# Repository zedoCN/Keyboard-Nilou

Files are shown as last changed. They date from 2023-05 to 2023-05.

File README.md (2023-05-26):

# Keyboard-Nilou  (KB-Nilou)
 
## 描述  
### 目前实现的功能：  
* usb键盘模拟  
* 系统音量调节  
* 上位机通讯(java kb-nilou-SDK)  
* 语音播放  
* rgb灯效  
* 热插拔键盘座  
* 震动反馈  

### 待填的坑：
* 第7K的扩展(懒得做了)  
* 官方的上位机软件(懒得写了)  

## PCB图：  
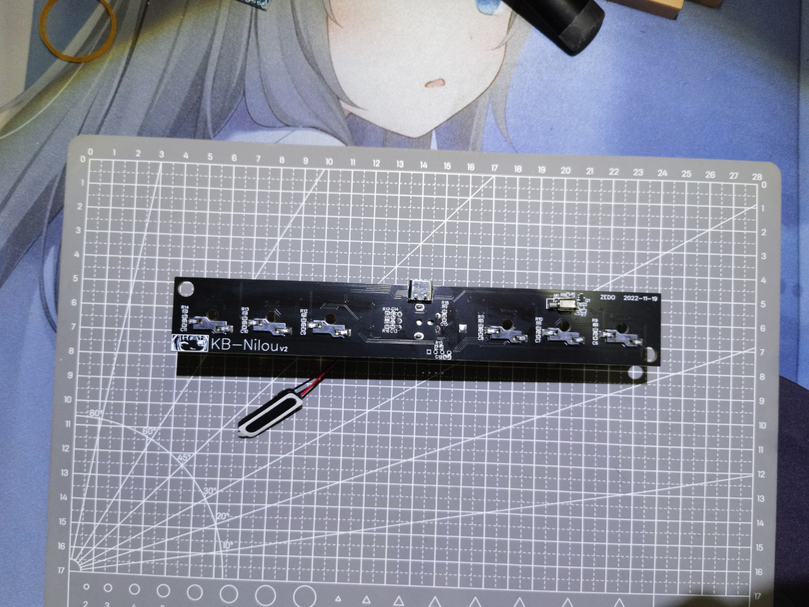
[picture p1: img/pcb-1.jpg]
   
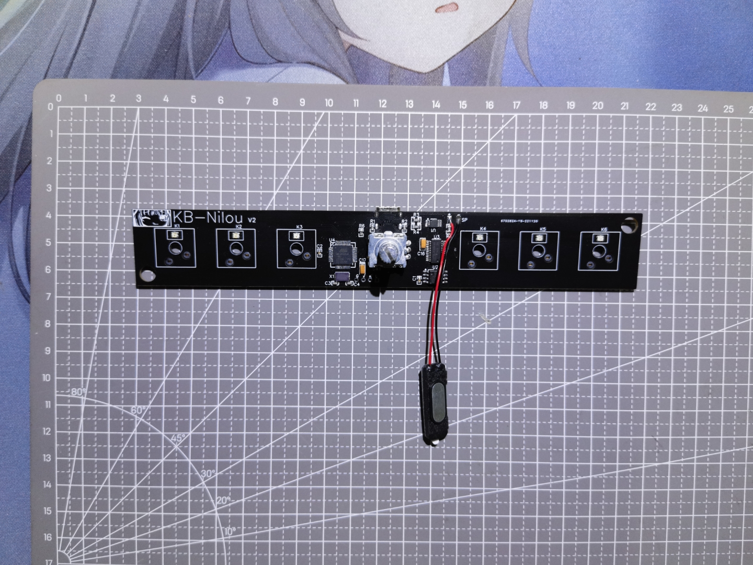
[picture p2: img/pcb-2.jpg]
   

## 渲染图：  

### (初代)  
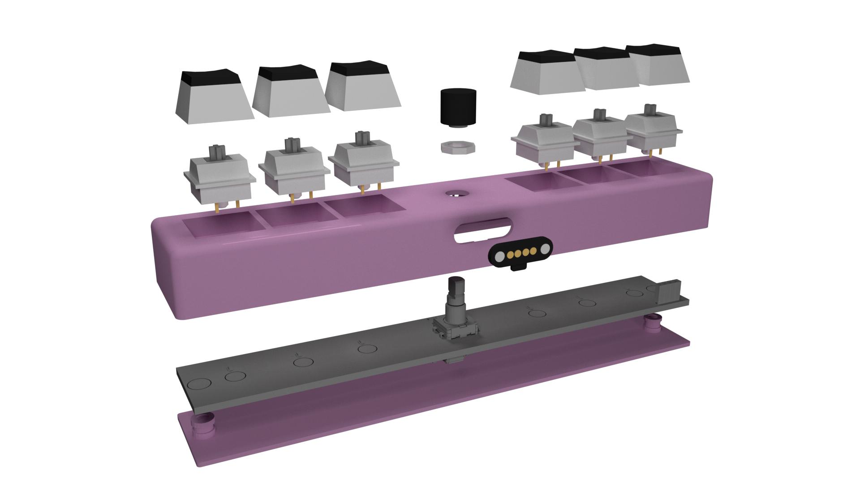
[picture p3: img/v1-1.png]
   

### (第一代)  
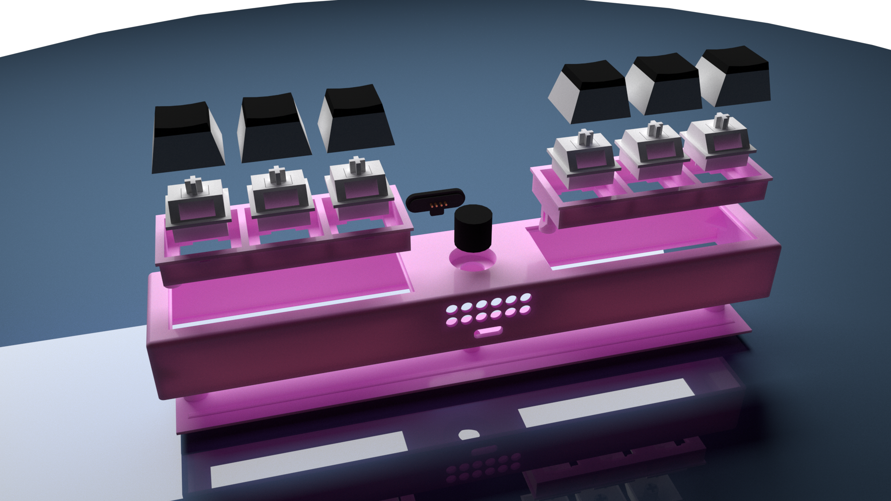
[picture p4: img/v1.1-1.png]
   

### (第二代)  
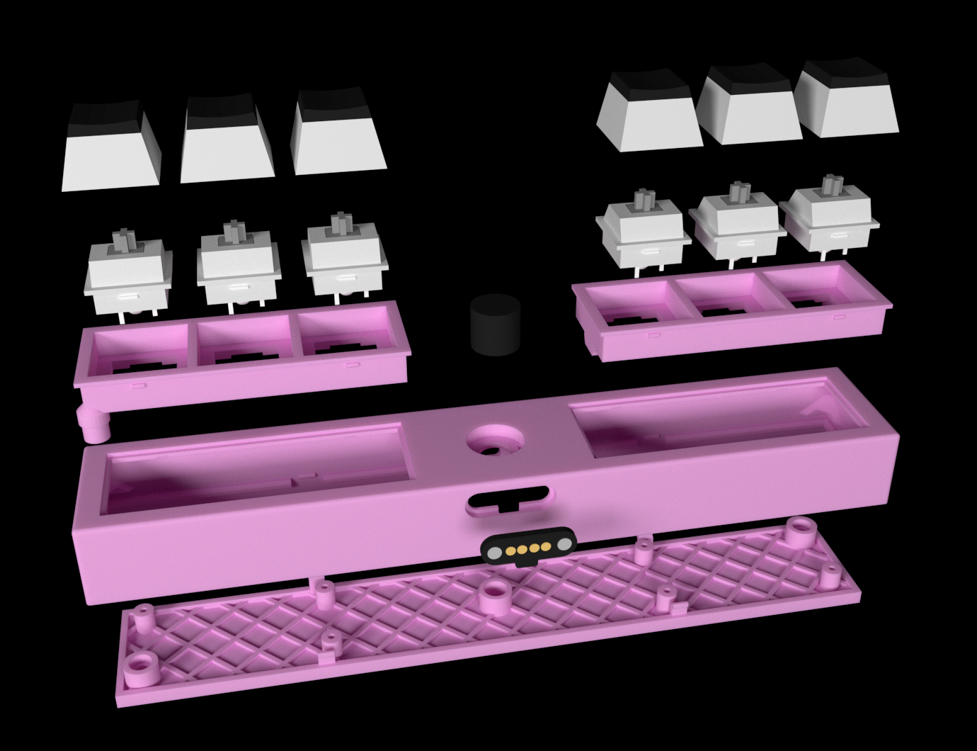
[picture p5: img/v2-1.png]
   

## 实物图：(白色和透明)  
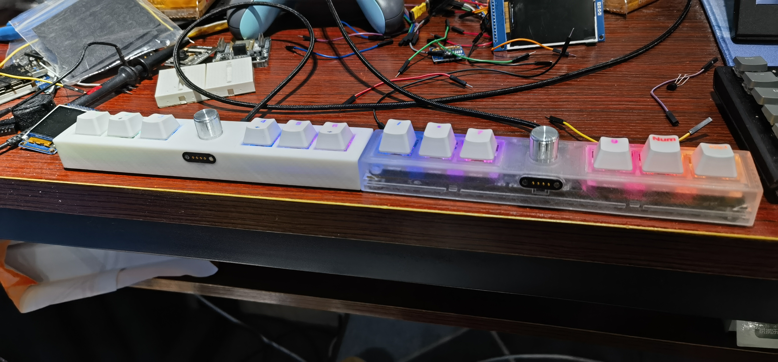
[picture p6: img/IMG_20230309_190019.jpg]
   
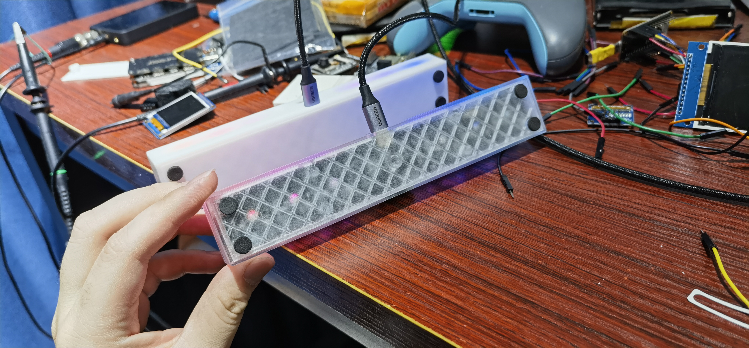
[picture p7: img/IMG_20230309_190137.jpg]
   

## 原理图 [嘉立创](https://oshwhub.com/zedo_cn/jian-pan-wai-she)
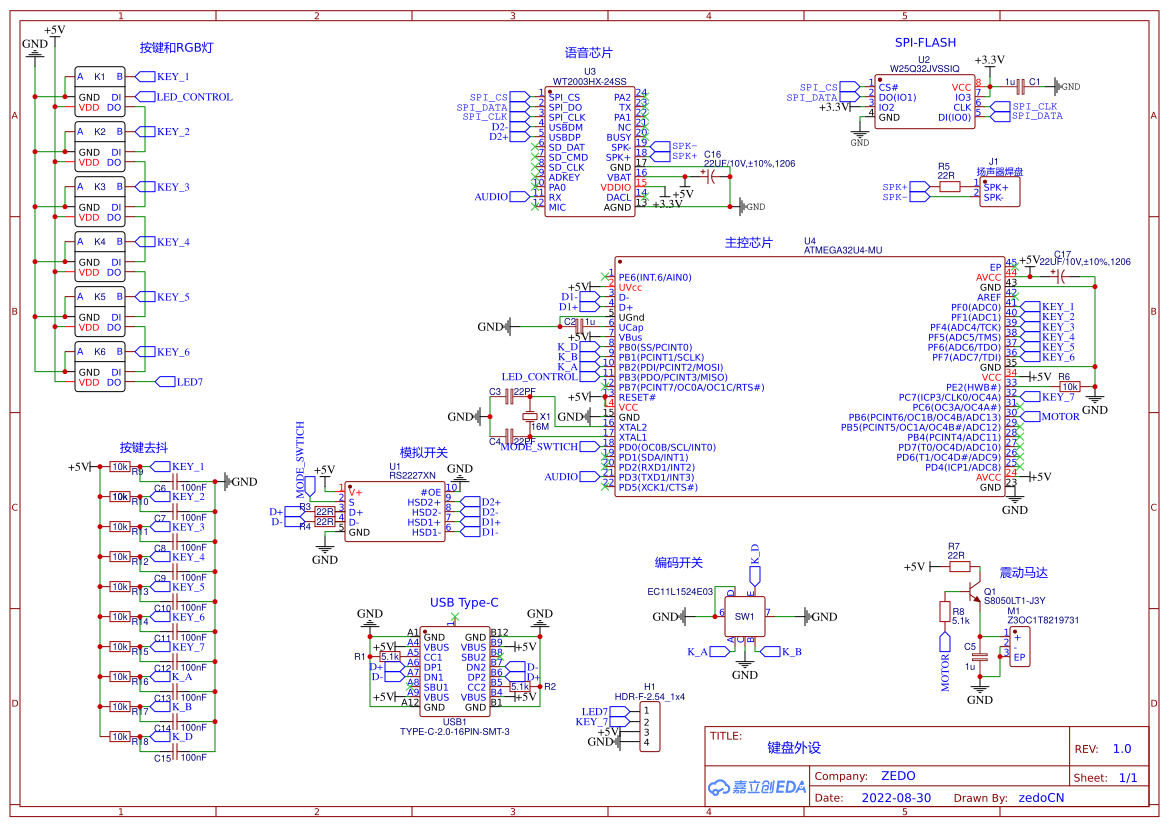
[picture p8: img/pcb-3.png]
   
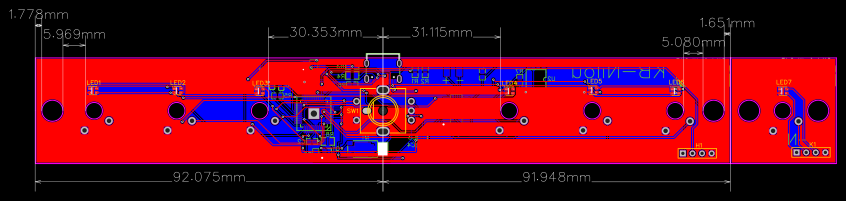
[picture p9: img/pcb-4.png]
   
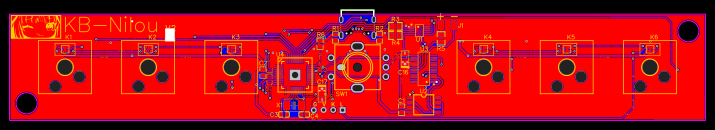
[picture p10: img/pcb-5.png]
   

## 所有的音频

* key音
    > * Kll.mp3  key音
    > * Knya.mp3  key音
    > * Kosu.mp3  key音
    > * Krachel.mp3  key音
    > * Ktshe.mp3  key音
* 其他
    > * Wel.mp3  欢迎
    > * OK.mp3  好
    > * UDSD.mp3  了解
    > * choose.mp3  选择音效
    > * HOc.mp3  上位机连接
    > * HOd.mp3  上位机断开连接
* 数字
    > * Nu0.mp3  数字0
    > * ...
    > * Nu10.mp3  数字10
* MCh.mp3  模式选择
    > * MAu.mp3  音频编辑模式
    > * MNo.mp3  普通模式
    > * MSe.mp3  设置模式
    >   > * SCh.mp3  设置选择
    >   > * SVo.mp3  音量设置
    >   > * Ske.mp3  key音设置
    >   > * SLm.mp3  灯光模式
    >   >   > * SLm0.mp3  0无灯光
    >   >   > * SLm1.mp3  1常亮
    >   >   > * SLm2.mp3  2独亮
    >   >   > * SLm3.mp3  3独亮闪烁
    >   > * SLc.mp3  灯光颜色
    >   >   > * SLc0.mp3  0自定义颜色
    >   >   > * SLc1.mp3  1七彩渐变
    >   >   > * SLc2.mp3  2七彩渐变流水
    >   >   > * SLc3.mp3  3随机
    >   >   > * SLc4.mp3  4纯红
    >   >   > * ...
    >   >   > * SLc11.mp3  11纯白
    >   > * SLb.mp3  灯光亮度
    >   > * SEx.mp3  退出设置
    >   > * SSh.mp3  震动设置
    >   >   > * SSh0.mp3  0无震动
    >   >   > * SSh1.mp3  1轻震动
    >   >   > * SSh2.mp3  2重震动
    >   > * SEx.mp3  退出设置

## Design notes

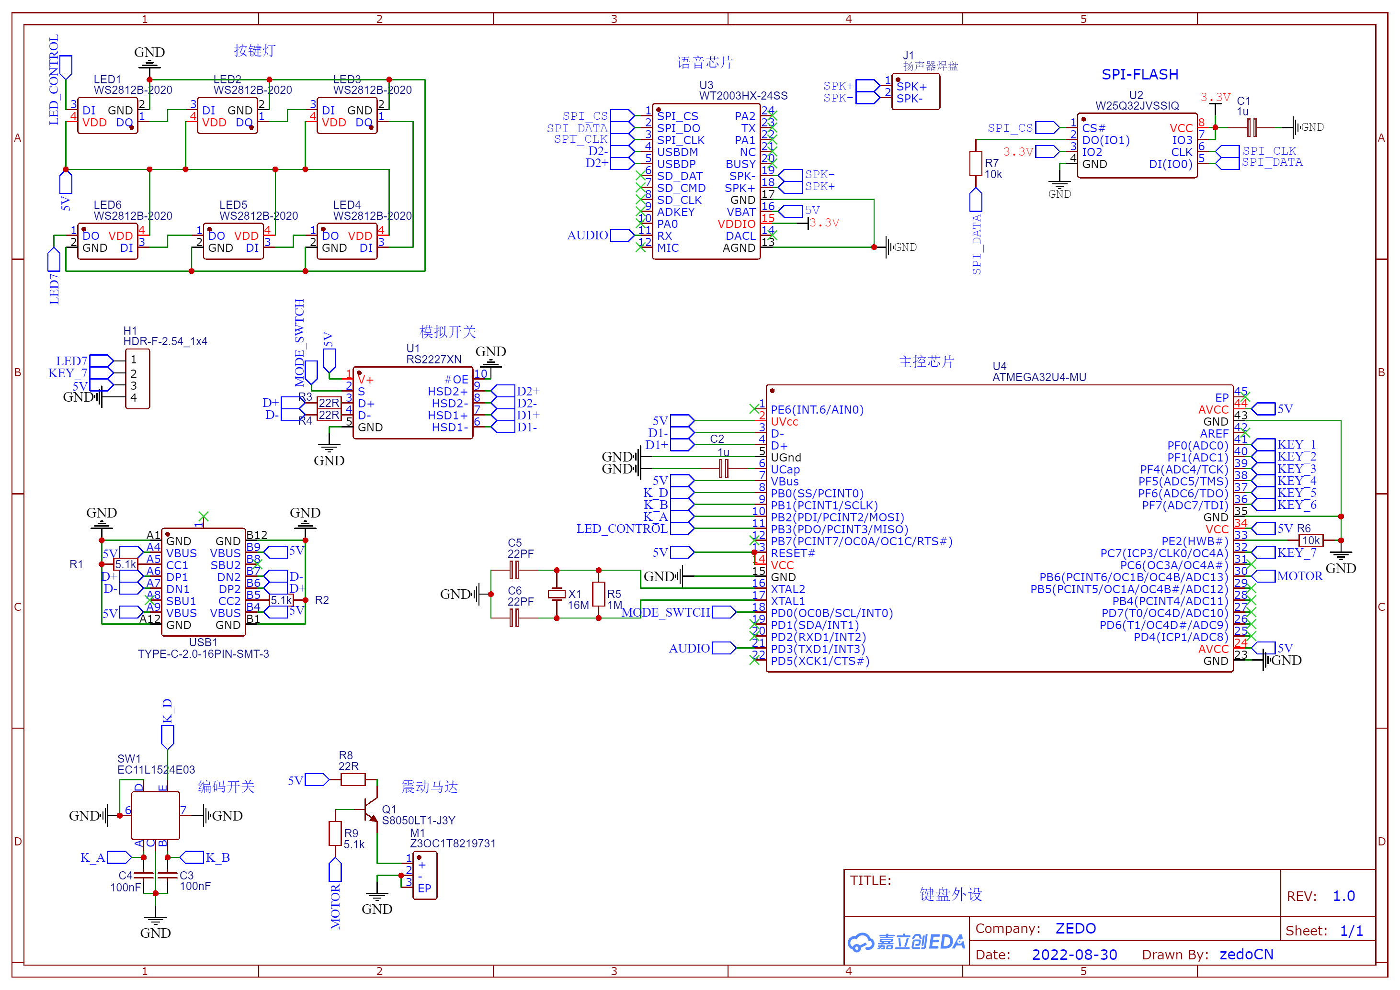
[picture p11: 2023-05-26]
Schematic_键盘外设_2022-09-01.png

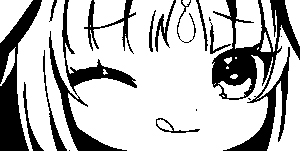
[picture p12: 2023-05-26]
100828284_p2.jpg

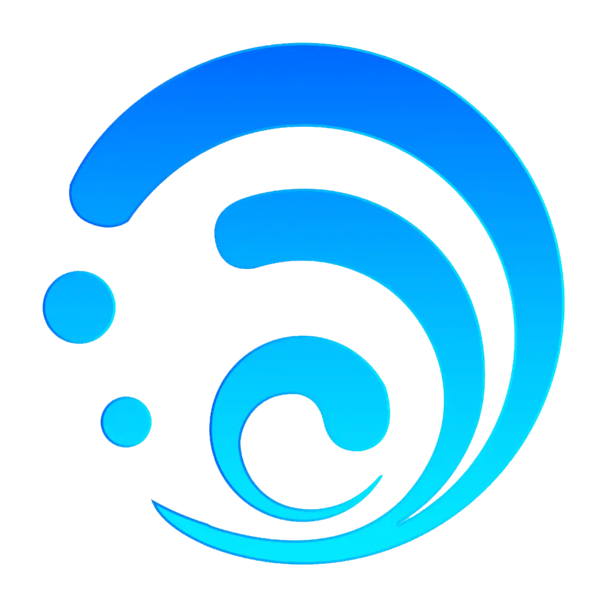
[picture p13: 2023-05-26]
水.png

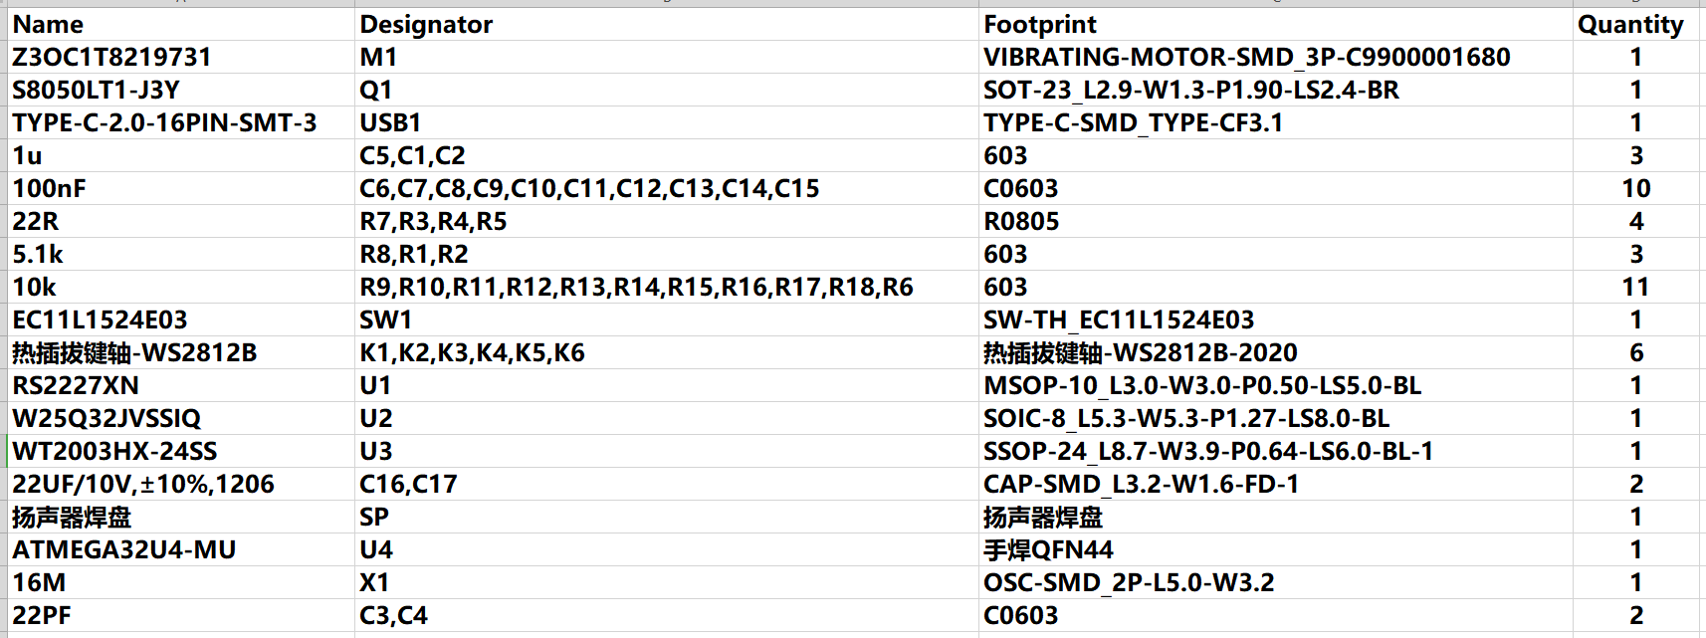
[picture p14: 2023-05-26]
KBNilou.png

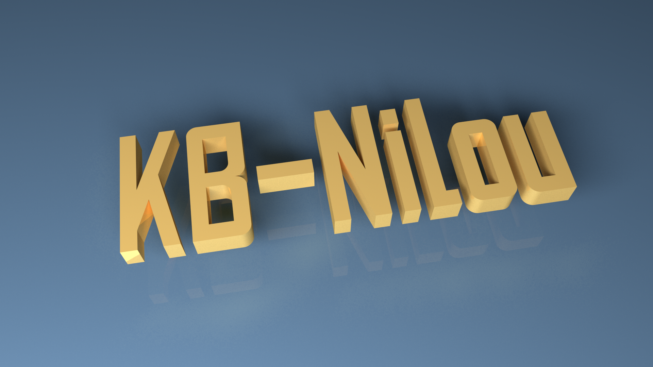
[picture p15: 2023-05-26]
KB-Nilou.png

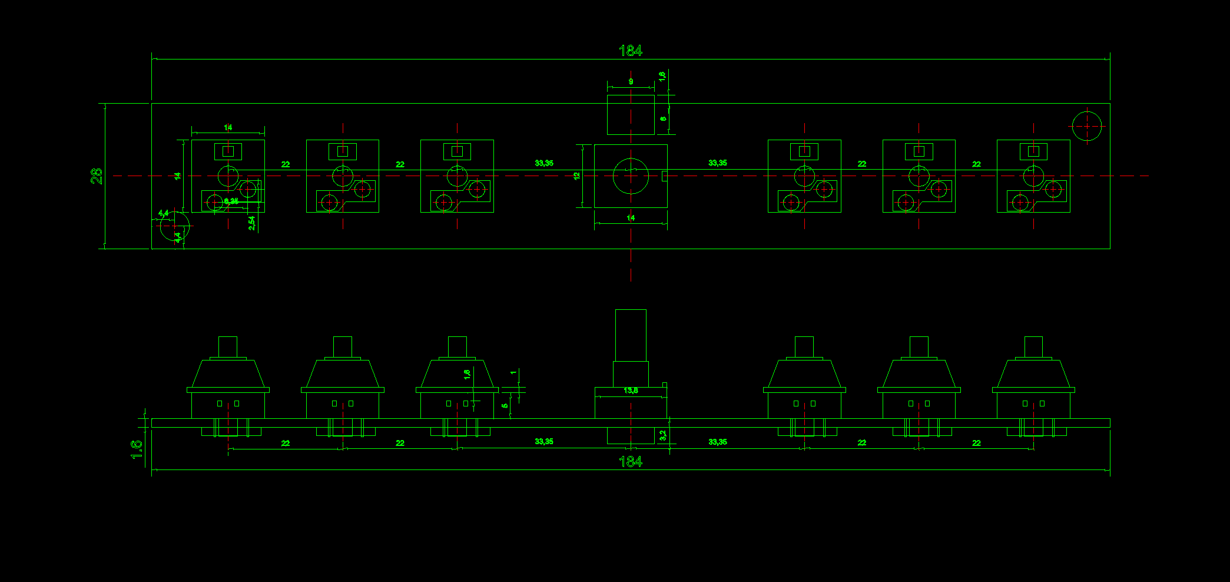
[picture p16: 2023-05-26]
KB-Nilou-v2.png

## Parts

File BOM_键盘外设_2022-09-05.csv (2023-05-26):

ID | Name | Designator | Footprint | Quantity | Manufacturer Part | Manufacturer | Supplier | Supplier Part | Price | Pins
1 | 1u | C1,C2 | 0603 | 2 |  |  |  |  |  | 2
2 | 100nF | C3,C4 | C0603 | 2 | 0603B104K500NT | FH | LCSC | C30926 | 0.0076 | 2
3 | 22PF | C5,C6 | C0603 | 2 |  |  |  |  |  | 2
4 | HDR-F-2.54_1x4 | H1 | HDR-F-2.54_1X4 | 1 |  |  | LCSC | C225501 | 0.5575 | 4
5 | 扬声器焊盘 | J1 | 扬声器焊盘 | 1 |  |  |  |  |  | 2
6 | WS2812B-2020 | LED1,LED2,LED3,LED4,LED5,LED6 | LED-SMD_4P-L2.0-W2.0-TL_WS2812B-2020 | 6 | WS2812B-2020 | Worldsemi | LCSC | C965555 | 0.6722 | 4
7 | Z3OC1T8219731 | M1 | VIBRATING-MOTOR-SMD_3P-C9900001680 | 1 | Z3OC1T8219731 | KOTL(金龙机电) | LCSC | C2894731 | 6.7 | 3
8 | S8050LT1-J3Y | Q1 | SOT-23_L2.9-W1.3-P1.90-LS2.4-BR | 1 | S8050LT1-J3Y | FH(风华) | LCSC | C2962087 | 0.1091 | 3
9 | 5.1k | R1,R2,R9 | 0603 | 3 |  |  |  |  |  | 2
10 | 22R | R3,R4,R8 | R0805 | 3 |  |  |  |  |  | 2
11 | 1M | R5 | 0603 | 1 |  |  |  |  |  | 2
12 | 10k | R6,R7 | 0603 | 2 |  |  |  |  |  | 2
13 | EC11L1524E03 | SW1 | SW-TH_EC11L1524E03 | 1 | EC11L1524E03 | ALPSALPINE(阿尔卑斯阿尔派) | LCSC | C2687297 | 5.71 | 7
14 | RS2227XN | U1 | MSOP-10_L3.0-W3.0-P0.50-LS5.0-BL | 1 | RS2227XN | RUNIC( ) | LCSC | C255478 | 1.93 | 10
15 | W25Q32JVSSIQ | U2 | SOIC-8_L5.3-W5.3-P1.27-LS8.0-BL | 1 | W25Q32JVSSIQ | WINBOND | LCSC | C82344 | 2.88 | 8
16 | WT2003HX-24SS | U3 | SSOP-24_L8.7-W3.9-P0.64-LS6.0-BL-1 | 1 | WT2003HX-24SS | null | LCSC | C2841000 |  | 24
17 | ATMEGA32U4-MU | U4 | 手焊QFN44 | 1 | ATMEGA32U4-MU | MICROCHIP | LCSC | C112161 | 28.25 | 45
18 | TYPE-C-2.0-16PIN-SMT-3 | USB1 | TYPE-C-SMD_TYPE-CF3.1 | 1 | TYPE-C-2.0-16PIN-SMT-3 | CIKI(皓富) | LCSC | C2987386 | 0.8706 | 17
19 | 16M | X1 | OSC-SMD_2P-L5.0-W3.2 | 1 | AA08000002 | TXC Corp | LCSC | C331621 | 2.53 | 2

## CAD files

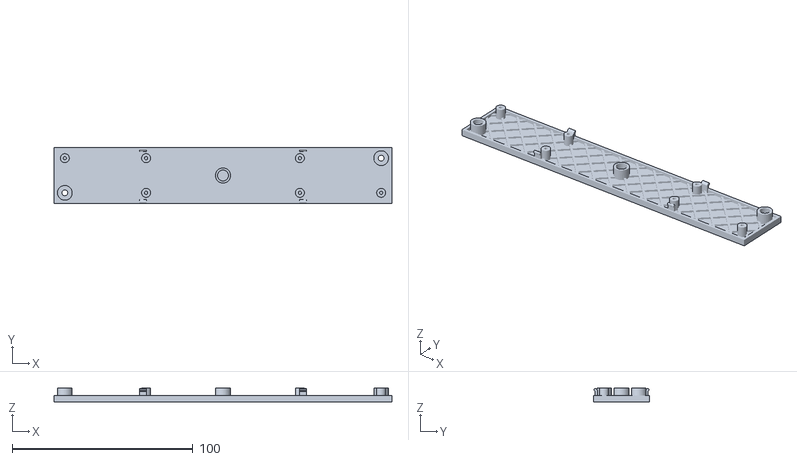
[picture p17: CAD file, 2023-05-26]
2.0/背板.stl
187.2 x 31.2 x 7.65

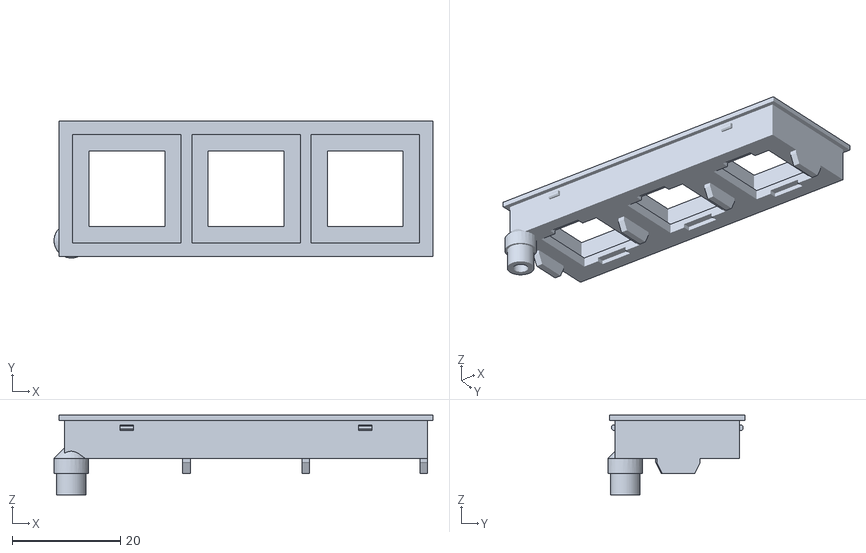
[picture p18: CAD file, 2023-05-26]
2.0/键盘座.stl
70.0 x 25.3 x 14.8

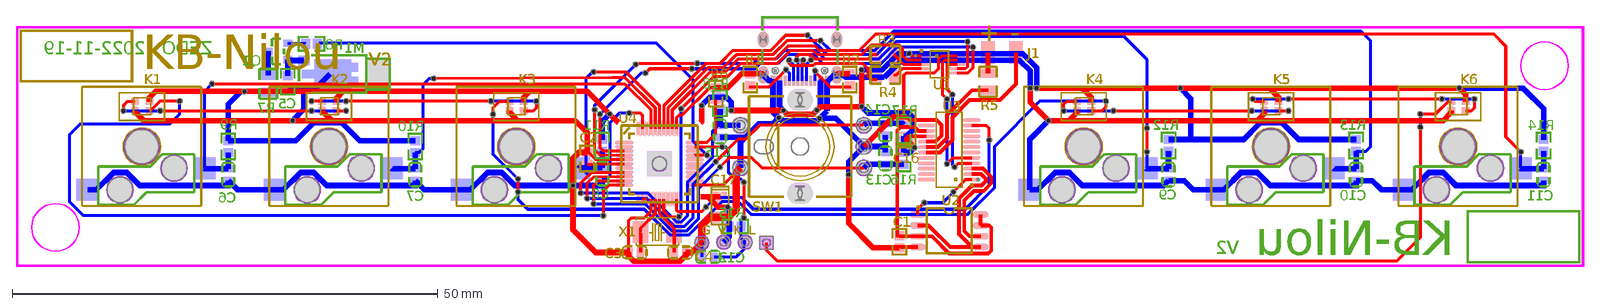
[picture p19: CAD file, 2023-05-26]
pcb/PCB_键盘外设_v2_2023-05-27.dxf
KB-Nilou
ZEDO 2022-11-19
V2
G V K L
M1
Q1
C5
C6
C7
C8
C9
C10
C11
C12
C13
C14
C15
R7
R8
R9
R10
R11
R12
R13
R14
R15
R16
R17
R18
J1
+
-
SW1
K1
K2
K3
K4
K5
K6
R1
C1
R2
R3
R4
U1
U2
U3
C16
C2
R5
R6
U4
X1
C3
C4
C17

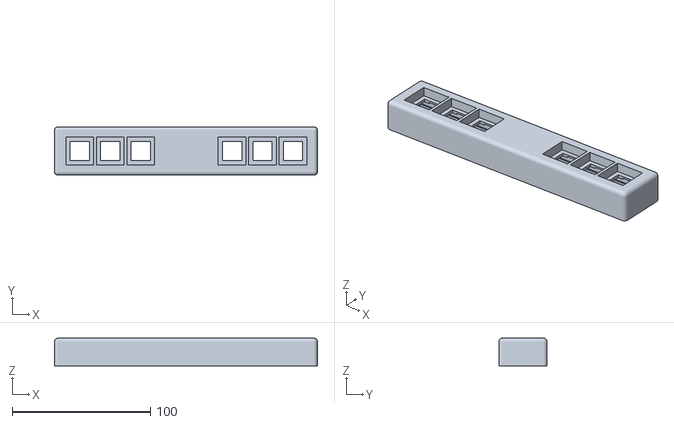
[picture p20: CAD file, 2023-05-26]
按键外设-本体.stl
190.0 x 35.0 x 20.0

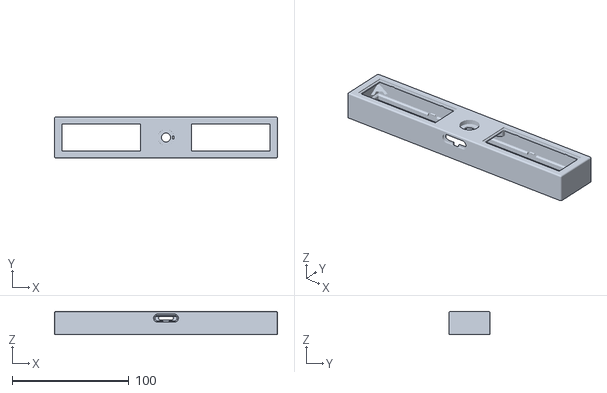
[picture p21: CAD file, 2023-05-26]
2.0/本体-圆角.stl
190.8 x 34.8 x 20.0

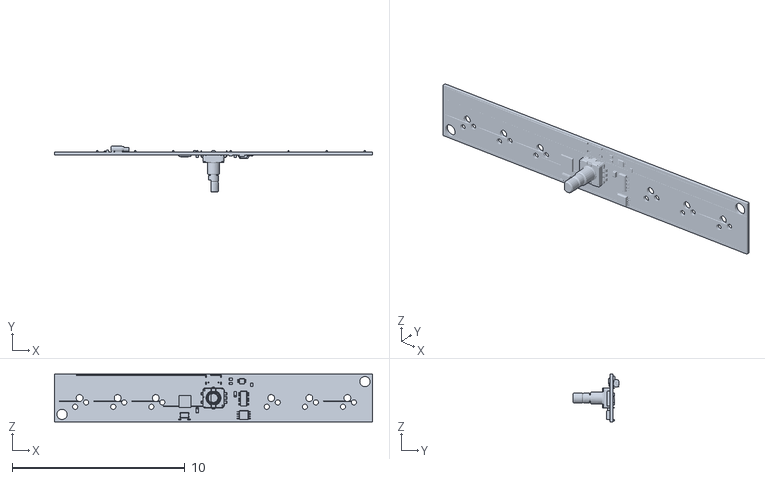
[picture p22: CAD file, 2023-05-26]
OBJ_PCB_键盘外设_1.1V.stl
18.4 x 2.66 x 2.78

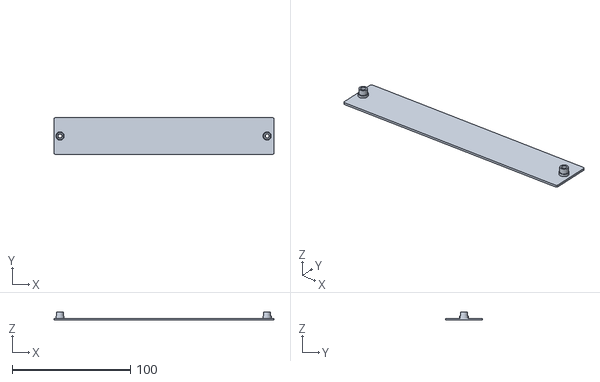
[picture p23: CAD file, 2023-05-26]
按键外设-背板.stl
186.0 x 31.0 x 7.09

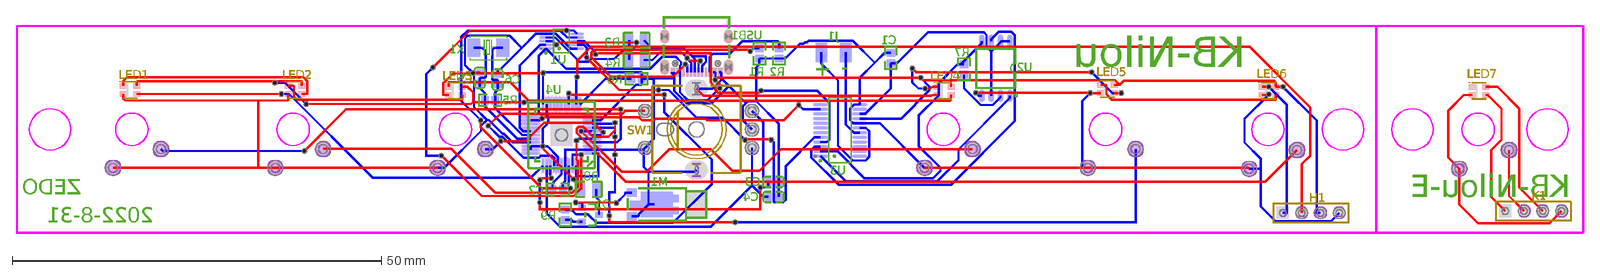
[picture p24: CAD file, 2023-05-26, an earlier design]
pcb/PCB_键盘外设_v1_2023-05-27.dxf
ZEDO
2022-8-31
KB-Nilou
KB-Nilou-E
USB1
J1
+
-
C1
C2
C3
C4
C5
C6
R1
R2
R3
R4
R5
R6
R7
R8
R9
U4
X1
M1
Q1
U1
U2
U3
LED7
K1
SW1
H1
LED1
LED2
LED3
LED4
LED5
LED6

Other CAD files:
NONAME_2.dwg
PCBB.dwg
PCB.dwg
KB-Nilou-v2.dwg

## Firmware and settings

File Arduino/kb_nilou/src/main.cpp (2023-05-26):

//------------库-------------
#include <Arduino.h>

#include "FastLED.h"            //FastLED库
#include "HID-Project.h"    //USB通讯库


#include "Z_CFCS.h"        //时钟库
#include "Z_EEPROM.h"        //存储库
#include "Z_Serial.h"       //串口库

//----------宏定义----------

// key数量
#define NUM_KEYS 7

// LED灯带型号
#define LED_TYPE WS2812B

//---------引脚定义---------
#define LED_CONTROL 14          //led控制
#define MODE_SWITCH 3           //模式开关
#define MOTOR 10                //震动马达
//#define AUDIO                 //音频通过串口进行通讯
#define K_D 17                  //旋转编码器D
#define K_B 15                  //旋转编码器B
#define K_A 16                  //旋转编码器A

#define KEY_0 A5                //key0-6
#define KEY_1 A4
#define KEY_2 A3
#define KEY_3 A2
#define KEY_4 A1
#define KEY_5 A0
#define KEY_6 13

//事件定义
enum NilouEvent {
    NE_KEY_PRESS,
    NE_KEY_RELEASE,
    NE_RE_ROTARY_CLOCKWISE,
    NE_RE_ROTARY_COUNTERCLOCKWISE,
    NE_RE_PRESS,
    NE_RE_LONG_PRESS
};

//指令定义
enum CMD {
    CMD_ERROR,
    CMD_HAND_SHAKE,
    CMD_EVENT,
    CMD_READ_C,
    CMD_WRITE_C,
    CMD_PLAY,
    CMD_OK,
    CMD_DEBUG,
    CMD_READ_E,
    CMD_WRITE_E,
    CMD_FLUSH,
    CMD_PING
};


//key引脚
uint8_t keys[NUM_KEYS] = {KEY_0, KEY_1, KEY_2, KEY_3, KEY_4, KEY_5, KEY_6};

//--------------存储变量---------------

//key全局统计
unsigned long keyPressAll = 0;

//key统计
unsigned long keyPress[NUM_KEYS] = {0, 0, 0, 0, 0, 0, 0};

//运行次数
unsigned long runCount;

//运行时间
unsigned long runTimes;

//key映射
char keyMapping[NUM_KEYS] = {'a', 's', 'd', 'j', 'k', 'l', ' '};

//key按下颜色
CRGB keyPressColor[NUM_KEYS];

//Key默认颜色
CRGB keyReleaseColor;

//音量              0-31
char volume = 0;

//灯光模式          0无灯光 1常亮 2独亮 3独亮闪烁
char lightMode = 0;

//灯光颜色          0自定义颜色 1七彩渐变 2七彩渐变流水 3随机 4纯红 5纯橙 6纯黄 7纯绿 8纯蓝 9纯粉 10纯紫 11白色
char lightColor = 0;

//灯光亮度  * 17    0-15
char lightBrightness = 0;


//震动模式          无震动 轻震动 重震动
char shakeMode = 0;

//key音             keyAu 0无声音 1-32
char keyAudio = 0;

//灯光过渡
float lightTransition = 0.2;

//按下灯光过渡
float keyTSPress = 0.25;

//松开灯光过渡
float keyTSRelease = 0.08;

//--------------内部变量----------------

//key状态
boolean keys_State[NUM_KEYS] = {false, false, false, false, false, false, false};

//key时间状态   负责独立特效
float keys_TimeState[NUM_KEYS] = {0, 0, 0, 0, 0, 0, 0};

//旋转编码器最后一次按下时间
unsigned long K_D_Last = 0;

//旋转编码器按下时间
unsigned long K_D_Press = 0;

//0空 1模式选择 2设置选择 3设置中
short menuMode = 0;

//0普通模式 1设置模式  2音频编辑模式
short modeSelect = 0;

//0音量设置 1灯光模式设置 2灯光颜色设置 3灯光亮度设置 4震动设置 5key音设置 6退出设置
short settingSelect = 0;

//旋转编码器上一次输出
boolean RE_Previous_Output;

// 光带leds
CRGB leds[NUM_KEYS];


int CID_CLOCK_Shake = -1;
int CID_CLOCK_play_num = -1;

//上位机连接超时
unsigned long HO_Time = 0;
bool HO = false;
/*
//------------------常用方法---------------

//取字符串中间      参数 | 字符串 字符串内容 | 字符串 左边内容 | 字符串 右边内容   |  返回 字符串 中间内容
String str_z(const String& str, const String& left, const String& right) {
    int lw = str.indexOf(left) + left.length();    //找查左边内容的结束位置
    String rstr = str.substring(lw, str.length()); //取str左边内容之后的字符串
    int rw = rstr.indexOf(right);                  //找查右边内容的起始位置
    if (str.substring(lw - left.length(), lw) != left || rw == 0) {              //判断欲寻找的内容是否存在
        return ""; //没找到 返回空
    }
    String back = rstr.substring(0, rw);
    return back; //返回值
}
*/

//------------------内部函数---------------------



CRGB EEPROM_Read_CRGB(uint16_t START_Byte) {
    return {
            Z_EEPROM_Read_byte(START_Byte),
            Z_EEPROM_Read_byte(START_Byte + 1),
            Z_EEPROM_Read_byte(START_Byte + 2)
    };
}


//音频命令  命令    参数    参数大小
void send_audio_cmd(uint8_t order, const char *p, uint8_t size) {
    uint8_t verify = 0;
    uint8_t len = 3 + size;
    uint8_t send_order[len + 2];
    send_order[0] = 0x7E;
    send_order[len + 1] = 0xEF;
    send_order[1] = len;
    send_order[2] = order;
    verify += len;
    verify += order;
    for (uint8_t i = 0; i < size; i++) {
        send_order[3 + i] = p[i];
        verify += p[i];
    }
    send_order[len] = verify;

    Serial1.write(send_order, sizeof(send_order));

}

//播放音频  音频名
void play_audio(const String &name) {
    char Buf[sizeof(name)];
    name.toCharArray(Buf, sizeof(name));
    send_audio_cmd(0xA1, Buf, sizeof(Buf));
}

//-----------------

//震动控制时钟
int CLOCK_Shake(int CID) {
    if (shakeMode == 0)
        return -1;
    digitalWrite(MOTOR, HIGH);
    CFCS_Delay((CFCS[CID].C_P == 0 ? 20 : 50) * shakeMode, CID);

    digitalWrite(MOTOR, LOW);
    return -1;
}


//震动  true轻震动    false重震动
void shake(boolean m) {
    Z_CFCS_Del(CID_CLOCK_Shake);
    CID_CLOCK_Shake = Z_CFCS_Add("Shake", 0, CLOCK_Shake);
    CFCS[CID_CLOCK_Shake].C_P = (m ? 0 : -1);
}

//设置音频音量  范围0-31
void set_aduio_voi(uint8_t v) {
    char order[] = {(char) v};
    send_audio_cmd(0xAE, order, sizeof(order));
}

//播放数字 0-99
void play_num(int num, int delay) {
    CFCS[CID_CLOCK_play_num].C_P = num;
    Z_CFCS_Set_Time(CID_CLOCK_play_num, delay);

}


void send_NilouEvent(char type, char num) {
    Z_Serial_Write_byte(0x03);//长度
    Z_Serial_Write_byte(CMD_EVENT);
    Z_Serial_Write_byte(type);
    Z_Serial_Write_byte(num);
    Z_Serial_Write_byte(0xff);//结束符
}

void send_error() {
    Z_Serial_Write_byte(0x01);//长度
    Z_Serial_Write_byte(CMD_ERROR);
    Z_Serial_Write_byte(0xff);//结束符
}

void send_ok() {
    Z_Serial_Write_byte(0x01);//长度
    Z_Serial_Write_byte(CMD_OK);
    Z_Serial_Write_byte(0xff);//结束符
}

void send_debug(const String &msg) {
    char len = msg.length() + 1;
    char cmsg[len];
    msg.toCharArray(cmsg, len);
    Z_Serial_Write_byte(len);//长度
    Z_Serial_Write_byte(CMD_DEBUG);
    for (char i = 0; i < len - 1; i++) {
        Z_Serial_Write_byte(cmsg[i]);//长度
    }

    Z_Serial_Write_byte(0xff);//结束符
}


//重载变量
void flush() {
    //读取设置
    {
        volume = Z_EEPROM_Read_byte(0);
        lightMode = Z_EEPROM_Read_byte(1);
        lightColor = Z_EEPROM_Read_byte(2);
        lightBrightness = Z_EEPROM_Read_byte(3);
        shakeMode = Z_EEPROM_Read_byte(4);
        keyAudio = Z_EEPROM_Read_byte(5);

        lightTransition = Z_EEPROM_Read_float(16);
        keyTSPress = Z_EEPROM_Read_float(20);
        keyTSRelease = Z_EEPROM_Read_float(24);


        keyPressAll = Z_EEPROM_Read_unsigned_long(32);
        {
            runCount = Z_EEPROM_Read_unsigned_long(36);
            runCount++;
            Z_EEPROM_Write_unsigned_long(36, runCount);
        }
        runTimes = Z_EEPROM_Read_unsigned_long(40);


        for (uint8_t i = 0; i < NUM_KEYS; i++) {
            keyPress[i] = Z_EEPROM_Read_unsigned_long(48 + i * 4);
            keyMapping[i] = Z_EEPROM_Read_byte(80 + i);
            keyPressColor[i] = EEPROM_Read_CRGB(112 + i * 3);
        }
        keyReleaseColor = CRGB(
                EEPROM.read(0x90),
                EEPROM.read(145),
                EEPROM.read(146)
        );
        set_aduio_voi(volume);
    }
}


//--------------旋转编码器事件---------------


void Event_HO(bool isConnect) {
    if (isConnect) {
        play_audio("HOc");
    } else {
        play_audio("HOd");
        for (size_t i = 0; i < Serial.available(); i++) {
            Z_Serial_Read_byte();
        }
        Serial.end();
        delay(1000);
        Serial.begin(115200);
    }

    //send_debug("连接" + String(isConnect));
}


//旋转
void RE_Event_Rotary(boolean isClockwise, int CID) {
    send_NilouEvent((isClockwise ? NE_RE_ROTARY_CLOCKWISE : NE_RE_ROTARY_COUNTERCLOCKWISE), 0x0);

    //Serial.println("[Event:RE_ROTARY][V:" + String(isClockwise) + "]");
    play_audio("CH");
    shake(true);
    Z_CFCS_Delay(100, CID);


    switch (menuMode) {
        case 0://0空
            for (char i = 0; i < 5; i++) {
                Consumer.write((isClockwise ? HID_CONSUMER_VOLUME_INCREMENT : HID_CONSUMER_VOLUME_DECREMENT));
            }
            break;
        case 1://1模式选择
            (isClockwise ? modeSelect++ : modeSelect--);
            if (modeSelect < 0)
                modeSelect = 2;
            modeSelect %= 3;
            switch (modeSelect) {
                case 0:
                    play_audio("MNo");
                    break;
                case 1:
                    play_audio("MSe");
                    break;
                case 2:
                    play_audio("MAu");
                    break;
            }
            break;
        case 2://2设置选择
            (isClockwise ? settingSelect++ : settingSelect--);
            if (settingSelect < 0)
                settingSelect = 6;
            settingSelect %= 7;
            //0音量设置 1灯光模式设置 2灯光颜色设置 3灯光亮度设置 4震动设置 5key音设置 6退出设置
            switch (settingSelect) {
                case 0://0音量设置
                    play_audio("SVo");
                    break;
                case 1://1灯光模式设置
                    play_audio("SLm");
                    break;
                case 2://2灯光颜色设置
                    play_audio("SLc");
                    break;
                case 3://3灯光亮度设置
                    play_audio("SLb");
                    break;
                case 4://4震动设置
                    play_audio("SSh");
                    break;
                case 5://5key音设置
                    play_audio("SKe");
                    break;
                case 6://6退出设置
                    play_audio("SEx");
                    break;
            }
            break;
        case 3://3设置中


            //0音量设置 1灯光模式设置 2灯光颜色设置 3灯光亮度设置 4震动设置 5key音设置 6退出设置
            switch (settingSelect) {
                case 0://0音量设置
                    (isClockwise ? volume++ : volume--);
                    if (volume < 0)
                        volume = 31;
                    volume %= 32;
                    set_aduio_voi(volume);
                    Z_EEPROM_Write_byte(0, volume);
                    play_num(volume, 100);
                    break;
                case 1://1灯光模式设置
                    (isClockwise ? lightMode++ : lightMode--);
                    if (lightMode < 0)
                        lightMode = 3;
                    lightMode %= 4;
                    Z_EEPROM_Write_byte(1, lightMode);
                    play_audio("SLm" + String((int) lightMode));
                    break;
                case 2://2灯光颜色设置
                    (isClockwise ? lightColor++ : lightColor--);
                    if (lightColor < 0)
                        lightColor = 11;
                    lightColor %= 12;
                    Z_EEPROM_Write_byte(2, lightColor);

                    if (lightColor == 0) {
                        for (uint8_t i = 0; i < NUM_KEYS; i++) {
                            keyPressColor[i] = EEPROM_Read_CRGB(112 + i * 3);
                        }
                        keyReleaseColor = EEPROM_Read_CRGB(144);

                    }

                    play_audio("SLc" + String((int) lightColor));
                    break;
                case 3://3灯光亮度设置
                    (isClockwise ? lightBrightness++ : lightBrightness--);
                    if (lightBrightness < 0)
                        lightBrightness = 15;
                    lightBrightness %= 16;
                    Z_EEPROM_Write_byte(3, lightBrightness);

                    play_num(lightBrightness, 400);
                    break;
                case 4://4震动设置
                    (isClockwise ? shakeMode++ : shakeMode--);
                    if (shakeMode < 0)
                        shakeMode = 2;
                    shakeMode %= 3;
                    play_audio("SSh" + String((int) shakeMode));
                    Z_EEPROM_Write_byte(4, shakeMode);
                    shake(true);
                    CFCS_Delay_Void(100, CID);
                    shake(true);
                    CFCS_Delay_Void(400, CID);
                    shake(false);
                    break;
                case 5://5key音设置
                    (isClockwise ? keyAudio++ : keyAudio--);
                    if (keyAudio < 0)
                        keyAudio = 32;
                    keyAudio %= 33;
                    Z_EEPROM_Write_byte(5, keyAudio);
                    play_audio("key" + String((int) keyAudio));
                    play_num(keyAudio, 600);
                    //CFCS_Delay(1000, CID);


                    break;
            }


            break;
    }


}

//按下
void RE_Event_Press(int CID) {
    //Serial.println("[Event:RE_PRESS]");
    send_NilouEvent(NE_RE_PRESS, 0x0);
    switch (menuMode) {
        case 0://0空
            shake(false);
            Consumer.write(HID_CONSUMER_MUTE);
            break;


    }
}

//长按
void RE_Event_Long_press(int CID) {
    //Serial.println("[Event:RE_LONG_PRESS]");
    send_NilouEvent(NE_RE_LONG_PRESS, 0x0);
    shake(true);
    Z_CFCS_Delay(50, CID);
    shake(true);


    switch (menuMode)//0空 1模式选择 2设置选择 3设置
    {
        case 0://0空
            play_audio("MCh");
            menuMode = 1;
            break;
        case 1://1模式选择
            //0普通模式 1设置模式  2音频编辑模式
            switch (modeSelect) {
                case 0:
                    play_audio("UDSD");//了解
                    menuMode = 0;
                    break;
                case 1:
                    play_audio("SCh");//设置选择
                    menuMode = 2;
                    settingSelect = 6;//默认退出
                    break;
                case 2:
                    play_audio("UDSD");//了解
                    char temp = lightBrightness;
                    lightBrightness = 0;
                    Z_CFCS_Delay(1000, CID);
                    digitalWrite(MODE_SWITCH, HIGH);//音频编辑
                    fill_solid(leds, NUM_KEYS, CRGB::Blue);
                    while (true) {
                        for (uint8_t i = 0; i < 255; i++) {
                            FastLED.setBrightness(i * (temp / 15.));
                            FastLED.show();
                            if (digitalRead(K_D) == LOW)
                                break;
                            delay(4);
                        }
                        for (uint8_t i = 0; i < 255; i++) {
                            FastLED.setBrightness((255 - i) * (temp / 15.));
                            FastLED.show();
                            if (digitalRead(K_D) == LOW)
                                break;
                            delay(4);
                        }
                        if (digitalRead(K_D) == LOW) {
                            for (uint8_t i = FastLED.getBrightness(); i > 0; i--) {
                                FastLED.setBrightness(i * (temp / 15.));
                                FastLED.show();
                                delay(4);
                            }
                            break;
                        }

                    }

                    digitalWrite(MODE_SWITCH, LOW);//音频编辑
                    Z_CFCS_Delay(1000, CID);
                    shake(true);
                    Z_CFCS_Delay(100, CID);
                    shake(true);
                    Z_CFCS_Delay(1000, CID);
                    lightBrightness = temp;
                    set_aduio_voi(volume);//设置音量
                    Z_CFCS_Delay(600, CID);
                    play_audio("MAu");//设置选择
                    break;
            }
            break;
        case 2://2设置选择
            //0音量设置 1灯光模式设置 2灯光颜色设置 3灯光亮度设置 4震动设置 5key音设置 6退出设置
            menuMode = 3;
            switch (settingSelect) {
                case 0:
                    play_num(volume, 400);
                    break;
                case 1:
                    play_audio("SLm" + String((int) lightMode));
                    break;
                case 2:
                    play_audio("SLc" + String((int) lightColor));
                    break;
                case 3:
                    play_num(lightBrightness, 400);
                    break;
                case 4:
                    play_audio("SSh" + String((int) shakeMode));
                    break;
                case 5:
                    play_audio("key" + String((int) keyAudio));
                    play_num(keyAudio, 600);
                    break;
                case 6:
                    play_audio("MSe");//了解
                    menuMode = 1;
                    break;
            }
            break;
        case 3://3设置中
            menuMode = 2;
            //play_audio("SCh");
            //Z_CFCS_Delay(2000, CID);
            //0音量设置 1灯光模式设置 2灯光颜色设置 3灯光亮度设置 4震动设置 5key音设置 6退出设置
            switch (settingSelect) {
                case 0://0音量设置
                    play_audio("SVo");
                    break;
                case 1://1灯光模式设置
                    play_audio("SLm");
                    break;
                case 2://2灯光颜色设置
                    play_audio("SLc");
                    break;
                case 3://3灯光亮度设置
                    play_audio("SLb");
                    break;
                case 4://4震动设置
                    play_audio("SSh");
                    break;
                case 5://5key音设置
                    play_audio("SKe");
                    break;
                case 6://6退出设置
                    play_audio("MSe");
                    break;
            }
            break;
    }

}

//--------------KEY事件---------------

//按下
void KEY_Event_Press(uint8_t i) {
    keyPressAll++;
    Z_EEPROM_Write_unsigned_long(32, keyPressAll);
    keyPress[i]++;
    Z_EEPROM_Write_unsigned_long(48 + 4 * i, keyPress[i]);
    if (lightColor == 3)//按下随机颜色
        keyPressColor[i] = CHSV(random8(255), 255, 255);
    BootKeyboard.press(keyMapping[i]);
    send_NilouEvent(NE_KEY_PRESS, i);
    //Serial.println("[Event:KEY_PRESS][V:" + String((int)i) + "]");
    play_audio("key" + String((int) keyAudio));

}

//松开
void KEY_Event_Release(uint8_t i) {
    BootKeyboard.release(keyMapping[i]);
    send_NilouEvent(NE_KEY_RELEASE, i);
    //Serial.println("[Event:KEY_RELEASE][V:" + String((int)i) + "]");
}



//-----------------时钟-------------------
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
void loop() {
    //时钟函数调用系统
    Z_CFCS_LOOP(-1);



    //key状态检测
    for (size_t i = 0; i < sizeof(keys); i++) {
        if (digitalRead(keys[i]) == LOW) {
            if (keys_State[i]) {
                keys_State[i] = !keys_State[i];
                KEY_Event_Press(i);
            }
        } else {
            if (!keys_State[i]) {
                keys_State[i] = !keys_State[i];
                KEY_Event_Release(i);
            }
        }

    }

}

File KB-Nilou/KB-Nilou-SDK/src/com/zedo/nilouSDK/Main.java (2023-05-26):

package com.zedo.nilouSDK;

public class Main {
    public static void main(String[] args) throws InterruptedException {
        Nilou nilou = new Nilou();


        nilou.openNilou("COM3");
        nilou.useDefaultInit();
        nilou.addEventListener((nilouEvent, index) -> {
            System.out.println(nilouEvent + " " + index);
        });
        nilou.closeNilou();
        //nilou.SetKeyPressAllCount(0);
        /*System.out.println(BytesUtils.bytes2fStr(nilou.readBytes((byte) 16, (byte) 4)));
        nilou.writeBytes((byte) 16,BytesUtils.float2bytesA(0.2f));
        System.out.println(BytesUtils.bytes2fStr(nilou.readBytes((byte) 16, (byte) 4)));
        System.out.println(BytesUtils.bytes2float(nilou.readBytes((byte) 16, (byte) 4)));*/
        //nilou.flush();
        //nilou.useDefaultInit();
        //nilou.setKeyReleaseColor(new Color(10,20,30));
        //nilou.flush();
        /*for (int i = 0; i < 16; i++) {
            //nilou.writeBytes(i * 16,new byte[16]);
            System.out.println(BytesUtils.bytes2fStr(nilou.readBytes(i * 16, 16)));
        }*/

        /*while (true) {
            //nilou.writeColor((byte) 0,new Color(new Random().nextInt(255*255*255)));
            System.out.println(nilou.getRunCount());
            nilou.ping();
            Thread.sleep(400);
        }*/
        //Nilou.writeBytes((byte) 0,new byte[]{20});
        //Nilou.flush();
        //System.out.println(Nilou.readBytes((byte) 0,new byte[]{2}););
        /*System.out.println(Nilou.readColor((byte) 0));
        Nilou.writeColor((byte) 0,new Color(255,0,0));
        Nilou.writeColor((byte) 1,new Color(0,255,0));
        Nilou.playAudio("Wel");
        */
        //Nilou.writeBytes((byte) 10, new byte[]{(byte) 0xff, (byte) 0xff});
        //System.out.println("输出:"+BytesUtils.bytes2fStr(Nilou.readBytes((byte) 10, (byte) 6)));
        //Nilou.getStatistics();
    }
}
